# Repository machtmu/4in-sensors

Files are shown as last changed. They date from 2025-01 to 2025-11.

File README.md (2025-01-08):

# Sensors Module Repository

Use Export KiCad Images Workflow

---

<div align="center">
  <div>
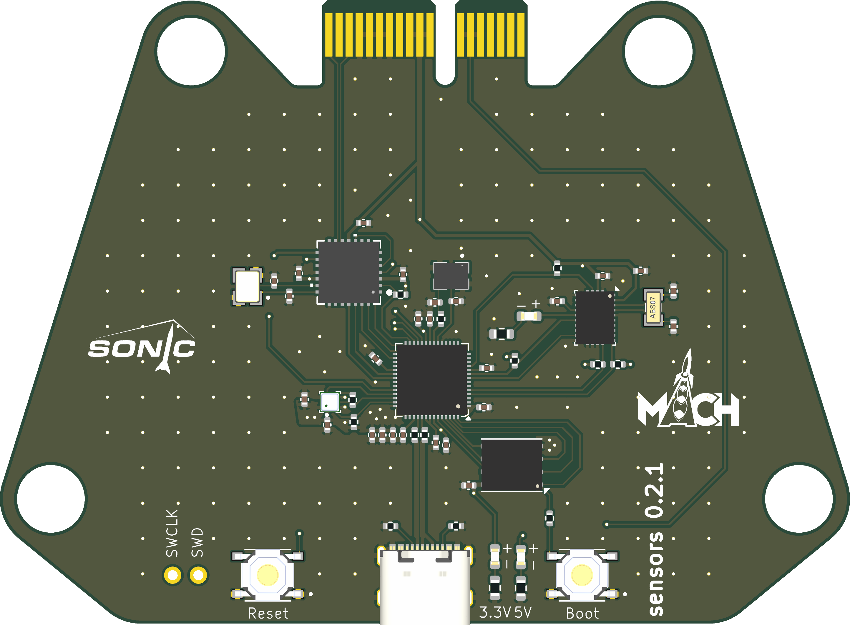
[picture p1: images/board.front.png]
    
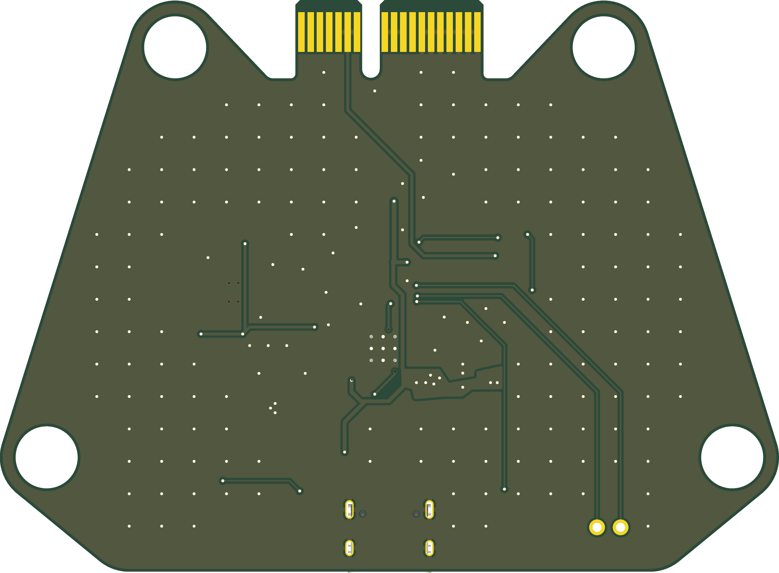
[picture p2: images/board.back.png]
    
    <p><em>3D Render</em></p>
  </div>
  <br>

  <div>
    Schematic<br>
    <p><em>Schematic</em></p>
  </div>
  <br>
  
  <div>
    Front
    Back<br>
    <em>Footprint</em>
  </div>
</div>

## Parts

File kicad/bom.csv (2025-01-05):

Reference | info | Value | Footprint | LCSC Part # | JLC Link | Digikey Link | basic? | price | Current Draw | Qty | DNP
Y2 | CAN Clock | X322516MLB4SI | X322516MLB4SI:OSC_X322516MLB4SI | C12668 | https://jlcpcb.com/partdetail/Yxc_CrystalOscillators-X322516MOB4SI/C12668 |  | no | C$0.0829 | 200 uW 3.3v | 1
Y1 | BNO055 Crystal | ABS07-32.768KHZ-T | ABS07-32.768KHZ-T:XTAL_ABS07-32.768KHZ-T | C130253 | https://jlcpcb.com/partdetail/AbraconLlc-ABS07_32_768KHZT/C130253 |  | no | C$0.6839 | 0.5 uW 3.3v | 1
X1 | MCU Crystal | ABM8-272-T3 | ABM8-272-T3:ABM8-272-T3_ABR | C20625731 | https://jlcpcb.com/partdetail/AbraconLlc-ABM8_272T3/C20625731 |  | no | C$0.6692 | 200 uW 3.3v | 1
U9 | CAN Controller/Tranceiver | MCP25625T-E/ML | MCP25625T_E_ML:QFN28_6X6MC_MCH | C191253 | https://jlcpcb.com/partdetail/MicrochipTech-MCP25625T_EML/C191253 |  | no | C$2.9424 | Con=10mA, Tra=70mA | 1
U8 | BNO055 | BNO055 | Package_LGA:LGA-28_5.2x3.8mm_P0.5mm | C93216 | https://jlcpcb.com/partdetail/BoschSensortec-BNO055/C93216 |  | no | C$14.0435 | 12.3mA | 1
U5 | BMP388 | BMP388 | BMP388:PQFN50P200X200X80-10N | C779278 | https://jlcpcb.com/partdetail/BoschSensortec-BMP388/C779278 |  | no | C$2.3423 | 800uA | 1
U4 | Flash | W25Q128JVP | Package_SON:WSON-8-1EP_6x5mm_P1.27mm_EP3.4x4.3mm | C190862 | https://jlcpcb.com/partdetail/WinbondElec-W25Q128JVPIQ/C190862 |  | no | C$1.0737 | 25mA | 1
U2 | MCU | RP2040 | Package_DFN_QFN:QFN-56-1EP_7x7mm_P0.4mm_EP3.2x3.2mm | C2040 | https://jlcpcb.com/partdetail/RaspberryPi-RP2040/C2040 |  | no | C$1.4190 | 20mA | 1
S1,S2 | Button | TS-1187A-B-A-B | TS-1187A-B-A-B:SW_TS-1187A-B-A-B | C318884 | https://jlcpcb.com/partdetail/XKBConnection-TS_1187A_B_AB/C318884 |  | yes | C$0.0242 |  | 2
R83,R87,R91 | 10k ohm | 10k | Resistor_SMD:R_0402_1005Metric | C25744 | https://jlcpcb.com/partdetail/26487-0402WGF1002TCE/C25744 |  | yes | C$0.0007 |  | 3
R220,R221,R222,R223 | 4.7k ohm | 4.7k | Resistor_SMD:R_0402_1005Metric | C25900 | https://jlcpcb.com/partdetail/26643-0402WGF4701TCE/C25900 |  | yes | C$0.0007 |  | 4
R203,R204 | 27 ohm | 27 | Resistor_SMD:R_0402_1005Metric | C25100 | https://jlcpcb.com/partdetail/25843-0402WGF270JTCE/C25100 |  | no | C$0.0007 |  | 2
R12,R30 | 1k ohm | 1k | Resistor_SMD:R_0402_1005Metric | C11702 | https://jlcpcb.com/partdetail/12256-0402WGF1001TCE/C11702 |  | yes | C$0.0007 |  | 2
R89 | 150 ohm | 150 | Resistor_SMD:R_0603_1608Metric | C22808 | https://jlcpcb.com/partdetail/23535-0603WAF1500T5E/C22808 |  | yes | C$0.0013 |  | 1
J6 | USB-C | USB_C_Receptacle_USB2.0_16P | Connector_USB:USB_C_Receptacle_Palconn_UTC16-G | C2765186 | https://jlcpcb.com/partdetail/ShouHan-TYPE_C_16PIN_2MD_073/C2765186 |  | no | C$0.0738 |  | 1
J4 | two headders | Conn_01x02 | Connector_PinHeader_2.54mm:PinHeader_1x02_P2.54mm_Vertical | n/a | n/a |  | n/a | n/a |  | 1 | DNP
J1 | PCIe fingers | Bus_PCI_Express_x1 | Connector_PCBEdge:BUS_PCIexpress_x1 | n/a | n/a |  | n/a | n/a |  | 1 | DNP
D88 | Red LED | LED | LED_SMD:LED_0603_1608Metric | C2286 | https://jlcpcb.com/partdetail/Hubei_KentoElec-KT0603R/C2286 |  | yes | C$0.0075 |  | 1
C85,C86,C94,C95 | 22pF Cap | 22p | Capacitor_SMD:C_0402_1005Metric | C1555 | https://jlcpcb.com/partdetail/1907-0402CG220J500NT/C1555 |  | yes | C$0.0077 |  | 4
C84,C208,C210 | 1uF Cap | 1u | Capacitor_SMD:C_0402_1005Metric | C52923 | https://jlcpcb.com/partdetail/53938-CL05A105KA5NQNC/C52923 |  | yes | C$0.0041 |  | 3
C40,C50,C51,C81,C82,C90,C92,C93,C206,C207,C209,C211,C212,C213,C214,C215,C216 | 100nF Cap | 100n | Capacitor_SMD:C_0402_1005Metric | C307331 | https://jlcpcb.com/partdetail/291005-CL05B104KB54PNC/C307331 |  | yes | C$0.0077 |  | 17
C10,C11 | 15pF Cap | 15p | Capacitor_SMD:C_0402_1005Metric | C1548 | https://jlcpcb.com/partdetail/1900-0402CG150J500NT/C1548 |  | yes | C$0.0013 |  | 2

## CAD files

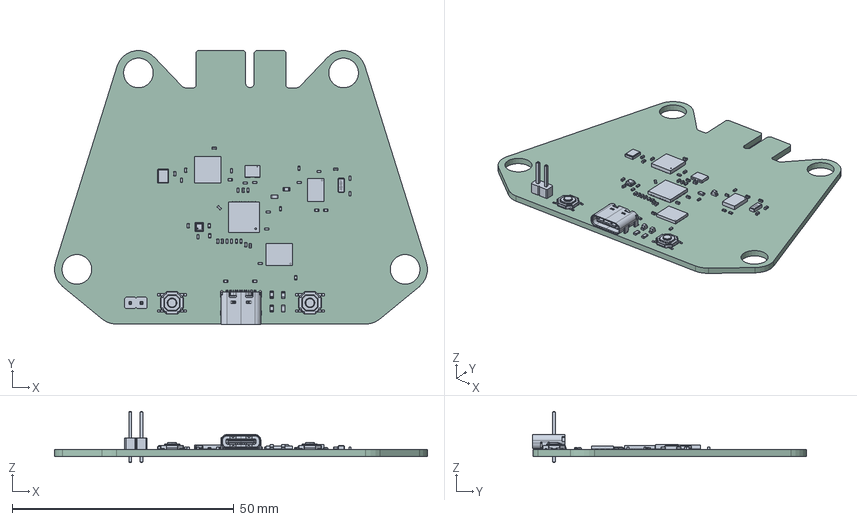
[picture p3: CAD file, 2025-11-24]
images/board.step
84.1 x 61.9 x 11.5 mm
WSON-8-1EP_6x5mm_P1.27mm_EP3.4x4.3mm
C_0402_1005Metric x 26
R_0402_1005Metric x 13
BMP388
X322516MLB4SI
TS-1187A-B-A-B x 2
R_0603_1608Metric x 3
LED_0603_1608Metric x 3
QFN28_6X6MC_MCH
USB_C_Receptacle_GCT_USB4105-xx-A_16P_TopMnt_Horizontal
ABM8-272-T3_ABR
LGA-28_5.2x3.8mm_P0.5mm
ABS07-32.768KHZ-T
QFN-56-1EP_7x7mm_P0.4mm_EP3.2x3.2mm
PinHeader_1x02_P2.54mm_Vertical
sensors_PCB

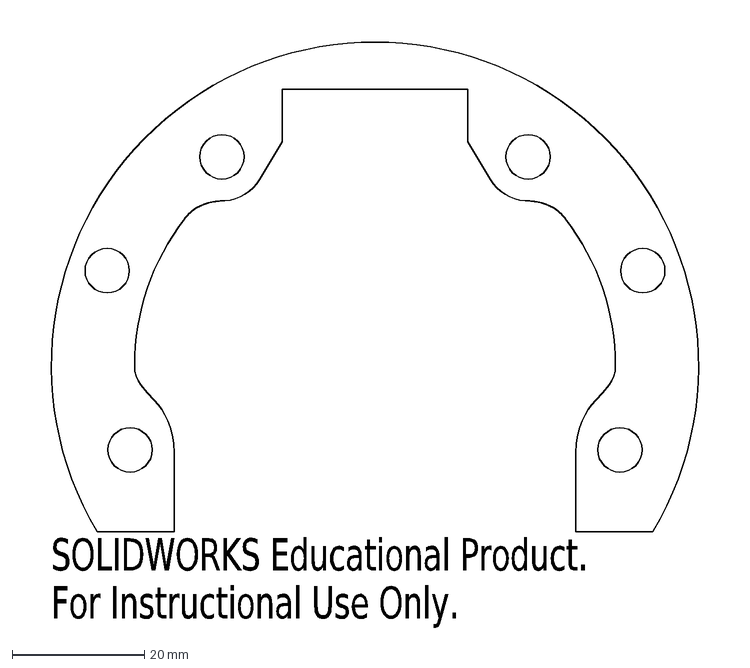
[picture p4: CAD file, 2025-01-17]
kicad/rack.DXF
SOLIDWORKS Educational Product.
For Instructional Use Only.

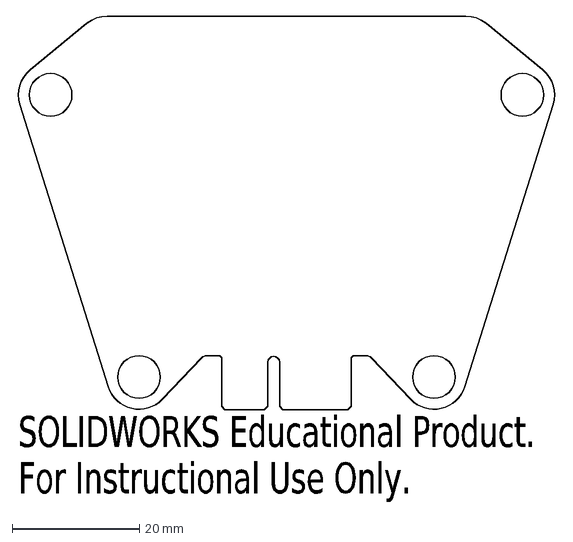
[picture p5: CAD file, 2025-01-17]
kicad/card.DXF
SOLIDWORKS Educational Product.
For Instructional Use Only.

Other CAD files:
solidworks/sensors.step

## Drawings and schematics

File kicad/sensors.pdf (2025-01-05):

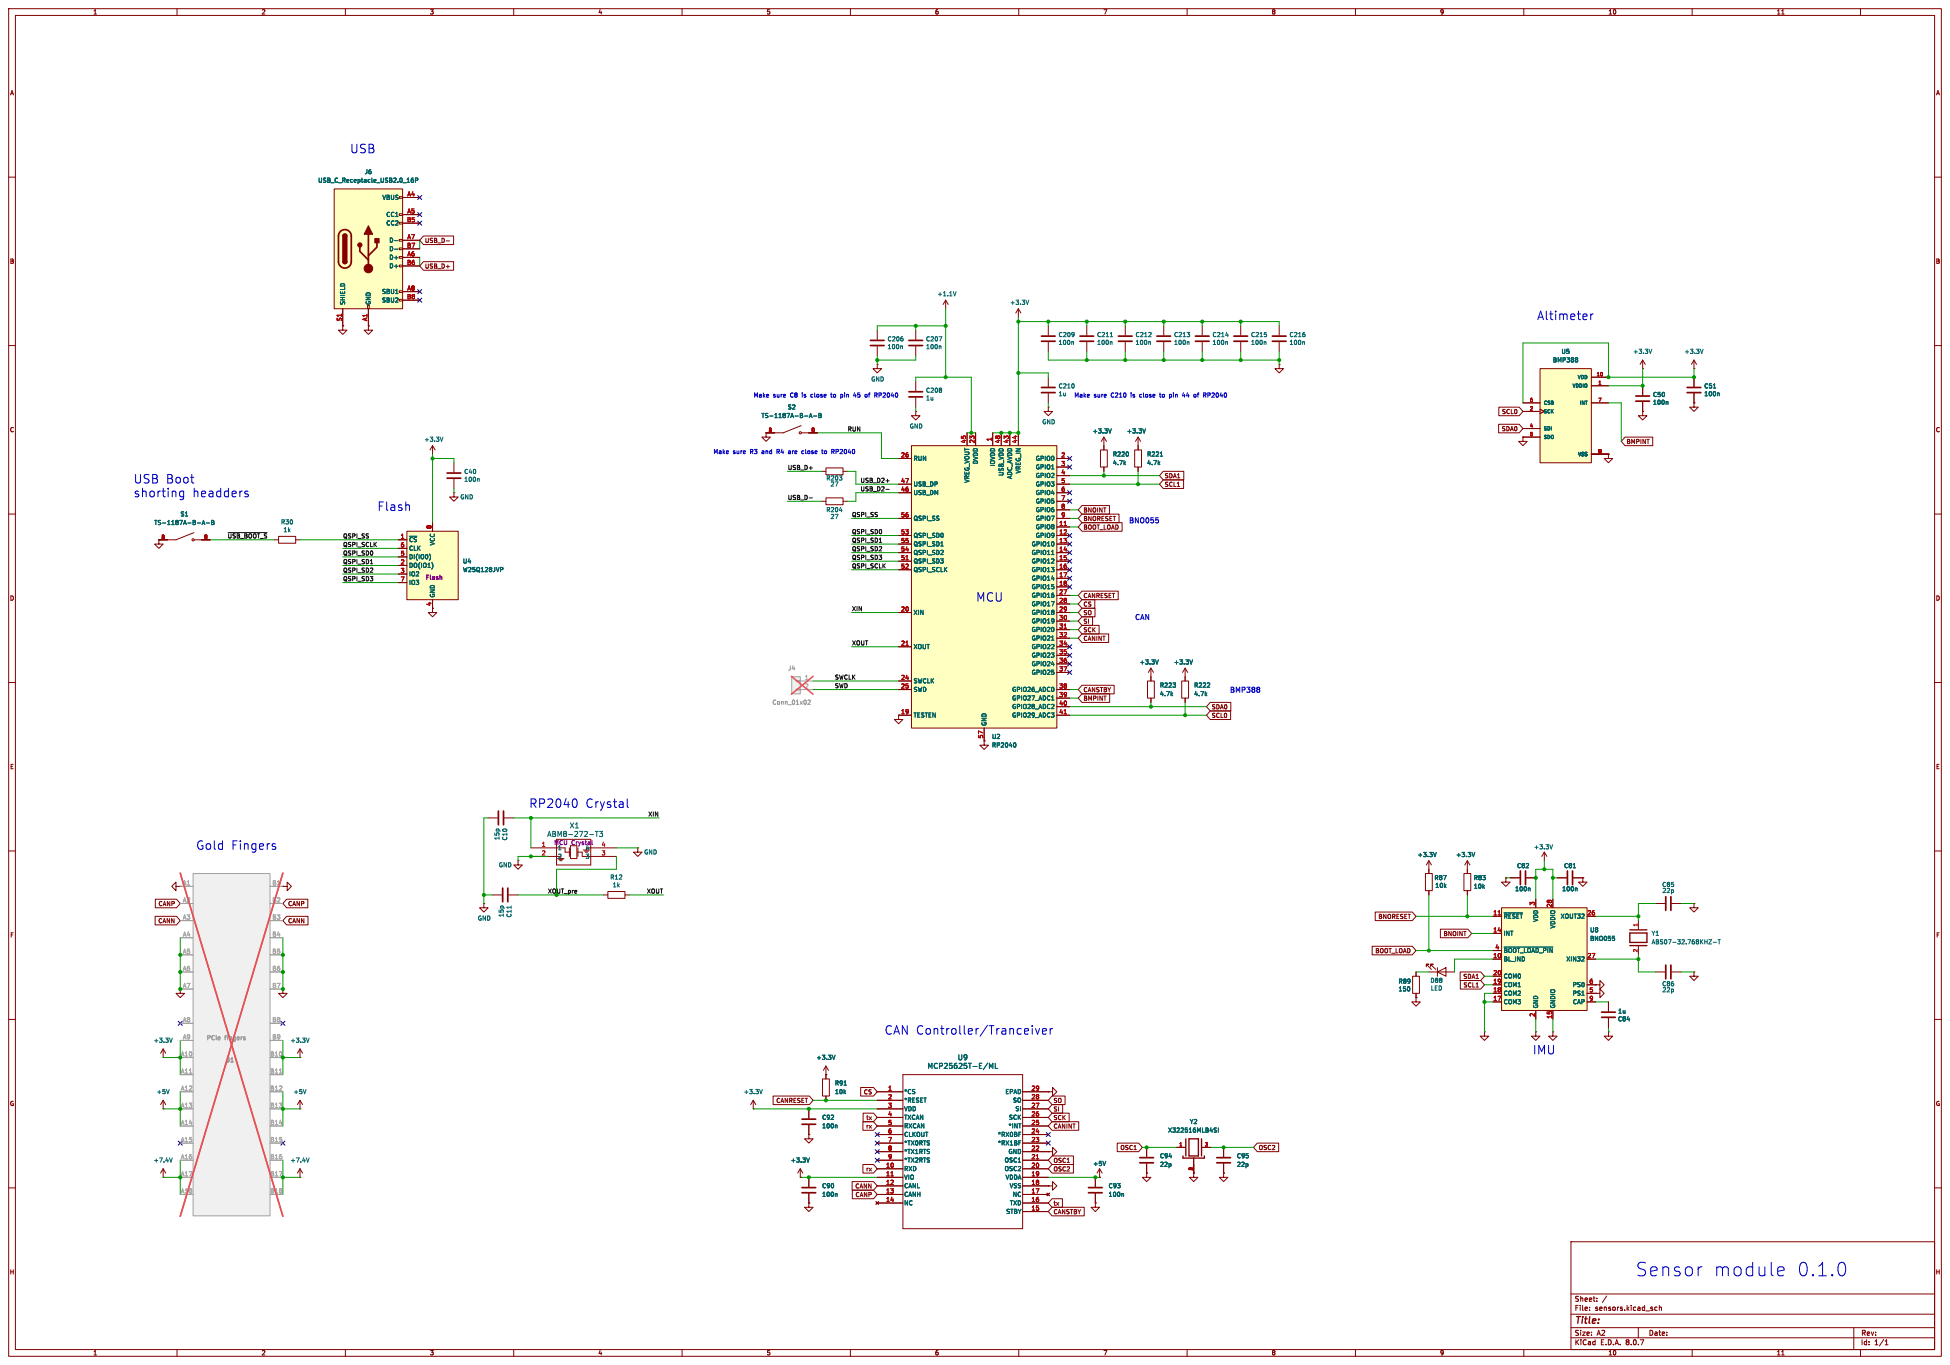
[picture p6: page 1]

Make sure R3 and R4 are close to RP2040 Make sure C8 is close to pin 45 of RP2040

Make sure C210 is close to pin 44 of RP2040 CAN Controller/Tranceiver

1 GPIO8 11 GPIO9 12 GPIO10 13 GPIO11 14 GPIO12 15 GPIO13 16 GPIO14 17 GPIO15 18 TESTEN 19 GPIO0 2 XIN 20 XOUT 21 DVDD 23 SWCLK 24 SWD 25 RUN 26 GPIO16 27 GPIO17 28 GPIO18 29 GPIO1 3 GPIO19 30 GPIO20 31 GPIO21 32 GPIO22 34 GPIO23 35 GPIO24 36 GPIO25 37 GPIO26_ADC0 38 GPIO27_ADC1 39 GPIO2 4 GPIO28_ADC2 40 GPIO29_ADC3 41 ADC_AVDD 43 VREG_IN 44 VREG_VOUT 45 USB_DM 46 USB_DP 47 USB_VDD 48 GPIO3 5 QSPI_SD3 51 QSPI_SCLK 52 QSPI_SD0 53 QSPI_SD2 54 QSPI_SD1 55 QSPI_SS 56 GND 57 GPIO4 6 GPIO5 7 GPIO6 8 GPIO7 9 U2 RP2040 R89

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

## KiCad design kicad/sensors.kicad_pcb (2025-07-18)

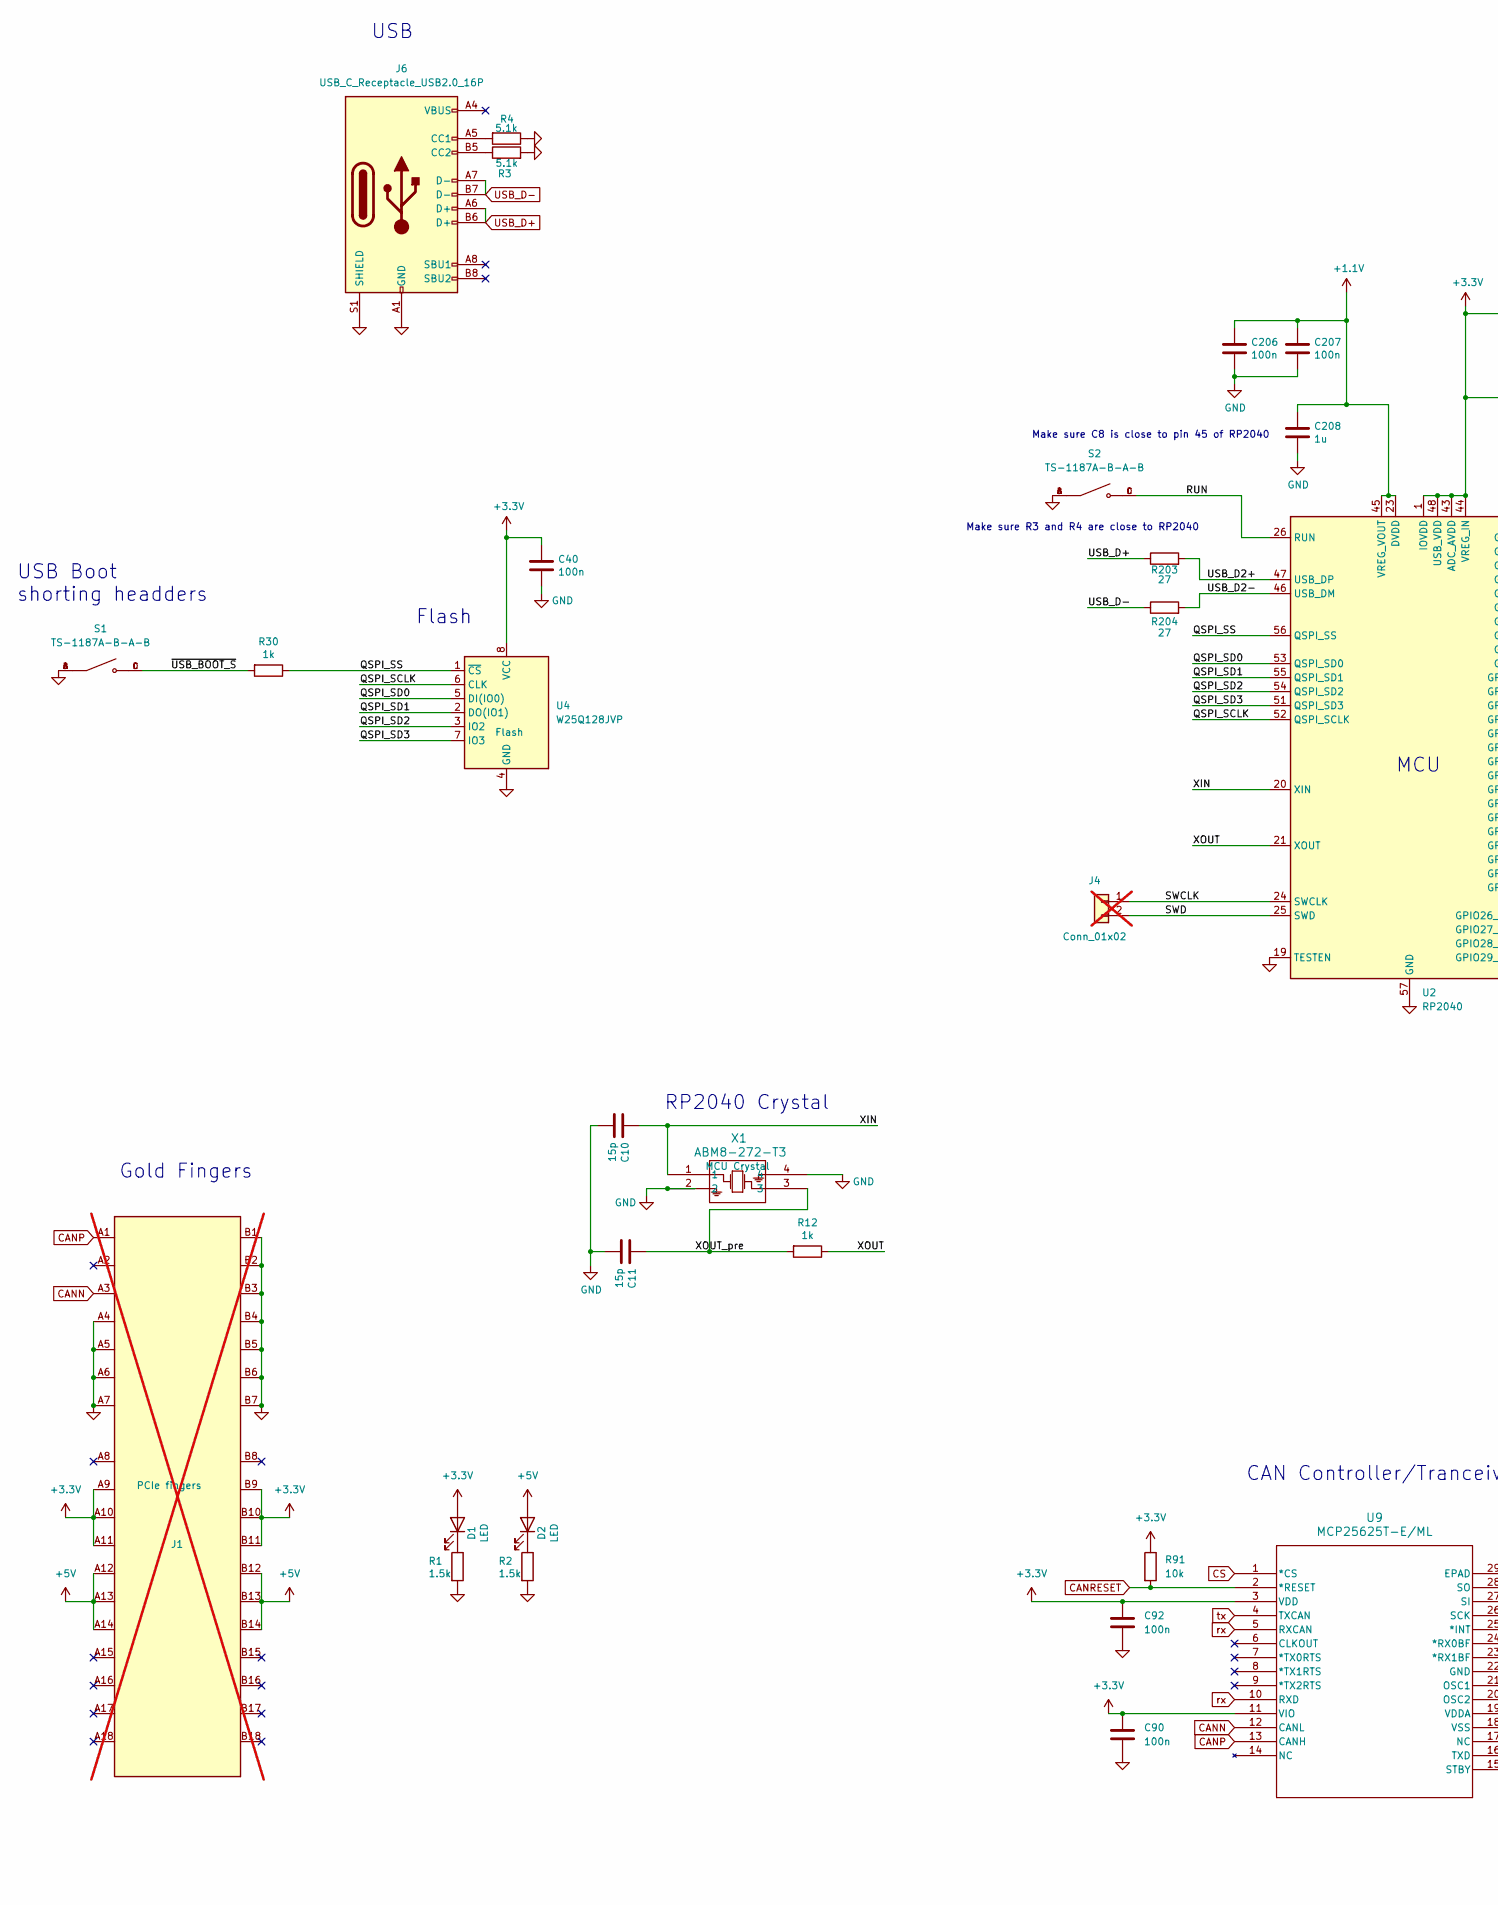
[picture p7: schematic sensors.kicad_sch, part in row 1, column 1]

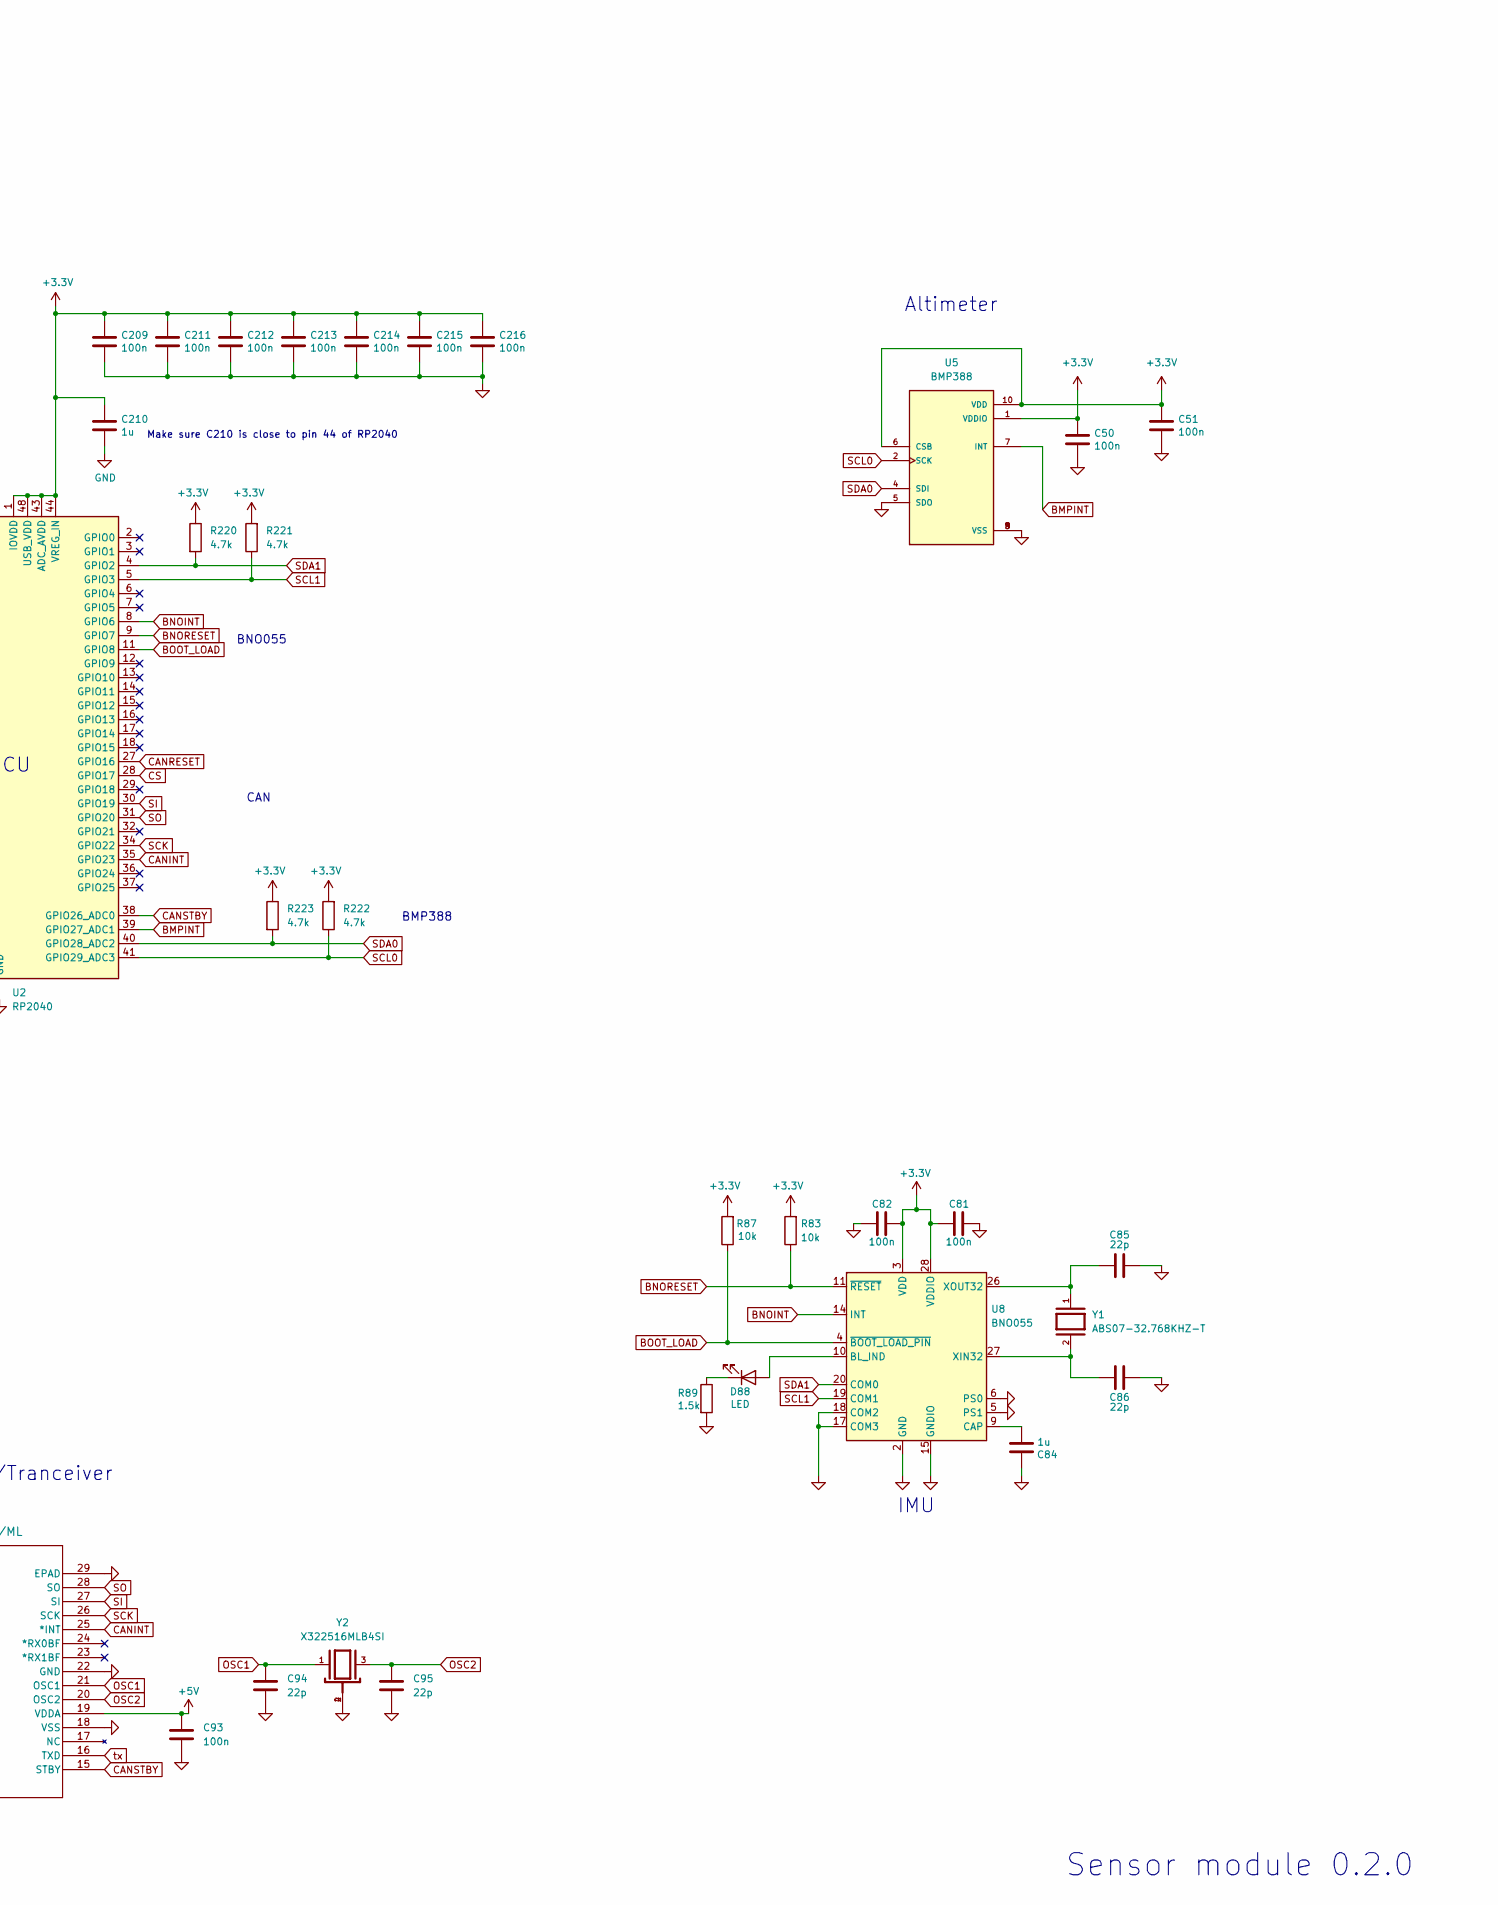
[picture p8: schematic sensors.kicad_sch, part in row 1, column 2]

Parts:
C10, C11: 15p; C_0402_1005Metric; LCSC Part # C1548
C40, C50, C51, C81, C82, C90, C92, C93, C206, C207, C209, C211, C212, C213, C214, C215, C216: 100n; C_0402_1005Metric; LCSC Part # C307331
C84, C208, C210: 1u; C_0402_1005Metric; LCSC Part # C52923
C85, C86, C94, C95: 22p; C_0402_1005Metric; LCSC Part # C1555
D1, D2, D88: LED; LED_0603_1608Metric; LCSC Part # C2286
J1: Bus_PCI_Express_x1; BUS_PCIexpress_x1; LCSC Part # n/a; not fitted
J4: Conn_01x02; PinHeader_1x02_P2.54mm_Vertical; LCSC Part # n/a; not fitted
J6: USB_C_Receptacle_USB2.0_16P; USB_C_Receptacle_Palconn_UTC16-G; LCSC Part # C2765186
R1, R2, R89: 1.5k; R_0603_1608Metric; LCSC Part # C22808
R3, R4: 5.1k; R_0402_1005Metric; LCSC Part # C25905
R12, R30: 1k; R_0402_1005Metric; LCSC Part # C11702
R83, R87, R91: 10k; R_0402_1005Metric; LCSC Part # C25744
R203, R204: 27; R_0402_1005Metric; LCSC Part # C25100
R220, R221, R222, R223: 4.7k; R_0402_1005Metric; LCSC Part # C25900
S1, S2: TS-1187A-B-A-B; SW_TS-1187A-B-A-B; PARTREV A0; LCSC Part # C318884
U2: RP2040; QFN-56-1EP_7x7mm_P0.4mm_EP3.2x3.2mm; LCSC C2040
U4: W25Q128JVP; WSON-8-1EP_6x5mm_P1.27mm_EP3.4x4.3mm; LCSC C190862
U5: BMP388; PQFN50P200X200X80-10N; PARTREV 1.1; LCSC Part # C779278
U8: BNO055; LGA-28_5.2x3.8mm_P0.5mm; LCSC C93216
U9: MCP25625T-E/ML; QFN28_6X6MC_MCH; LCSC Part # C191253
X1: ABM8-272-T3; ABM8-272-T3_ABR; LCSC Part # C20625731
Y1: ABS07-32.768KHZ-T; XTAL_ABS07-32.768KHZ-T; PARTREV 08.19.15; LCSC Part # C130253
Y2: X322516MLB4SI; OSC_X322516MLB4SI; PARTREV N/A; LCSC Part # C12668

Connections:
+1.1V: C206.1, C207.1, C208.1, U2.23 (DVDD), U2.45 (VREG_VOUT), U2.50 (DVDD)
+3.3V: C40.1, C50.1, C51.1, C81.1, C82.2, C90.1, C92.1, C209.1, C210.1, C211.1, C212.1, C213.1, C214.1, C215.1, C216.1, D1.2 (A), J1.A9 (+3.3V), J1.A10 (+3.3V), J1.A11 (~PERST), J1.B9 (JTAG1), J1.B10 (3.3Vaux), J1.B11 (~WAKE), R83.2, R87.2, R91.1, R220.1, R221.2, R222.2, R223.1, U2.1 (IOVDD), U2.10 (IOVDD), U2.22 (IOVDD), U2.33 (IOVDD), U2.42 (IOVDD), U2.43 (ADC_AVDD), U2.44 (VREG_IN), U2.48 (USB_VDD), U2.49 (IOVDD), U4.8 (VCC), U5.1 (VDDIO), U5.6 (CSB), U5.10 (VDD), U8.3 (VDD), U8.28 (VDDIO), U9.3 (VDD), U9.11 (VIO)
+5V: C93.1, D2.2 (A), J1.A12 (GND), J1.A13 (REFCLK+), J1.A14 (REFCLK-), J1.B12 (RSVD), J1.B13 (GND), J1.B14 (PETp0), U9.19 (VDDA)
/QSPI_SCLK: U2.52 (QSPI_SCLK), U4.6 (CLK)
/QSPI_SD0: U2.53 (QSPI_SD0), U4.5 (DI(IO0))
/QSPI_SD1: U2.55 (QSPI_SD1), U4.2 (DO(IO1))
/QSPI_SD2: U2.54 (QSPI_SD2), U4.3 (IO2)
/QSPI_SD3: U2.51 (QSPI_SD3), U4.7 (IO3)
/QSPI_SS: R30.1, U2.56 (QSPI_SS), U4.1 (~CS)
/RUN: S2.C, S2.D, U2.26 (RUN)
/SWCLK: J4.1, U2.24 (SWCLK)
/SWD: J4.2, U2.25 (SWD)
/USB_D2+: R203.2, U2.47 (USB_DP)
/USB_D2-: R204.2, U2.46 (USB_DM)
/XIN: C10.1, U2.20 (XIN), X1.1
/XOUT: R12.1, U2.21 (XOUT)
/XOUT_pre: C11.1, R12.2, X1.3
/~USB_BOOT_S: R30.2, S1.C, S1.D
BMPINT: U2.39 (GPIO27_ADC1), U5.7 (INT)
BNOINT: U2.8 (GPIO6), U8.14 (INT)
BNORESET: R83.1, U2.9 (GPIO7), U8.11 (~RESET)
BOOT_LOAD: R87.1, U2.11 (GPIO8), U8.4 (~BOOT_LOAD_PIN)
CANINT: U2.35 (GPIO23), U9.25 (*INT)
CANN: J1.A3 (+12V), U9.12 (CANL)
CANP: J1.A1 (~PRSNT1), U9.13 (CANH)
CANRESET: R91.2, U2.27 (GPIO16), U9.2 (*RESET)
CANSTBY: U2.38 (GPIO26_ADC0), U9.15 (STBY)
CS: U2.28 (GPIO17), U9.1 (*CS)
GND: C10.2, C11.2, C40.2, C50.2, C51.2, C81.2, C82.1, C84.1, C85.2, C86.1, C90.2, C92.2, C93.2, C94.2, C95.2, C206.2, C207.2, C208.2, C209.2, C210.2, C211.2, C212.2, C213.2, C214.2, C215.2, C216.2, J1.A4 (GND), J1.A5 (JTAG2), J1.A6 (JTAG3), J1.A7 (JTAG4), J1.B1 (+12V), J1.B2 (+12V), J1.B3 (+12V), J1.B4 (GND), J1.B5 (SMCLK), J1.B6 (SMDAT), J1.B7 (GND), J6.A1 (GND), J6.A12 (GND), J6.B1 (GND), J6.B12 (GND), J6.S1 (SHIELD), R1.2, R2.2, R3.2, R4.1, R89.2, S1.A, S1.B, S2.A, S2.B, U2.19 (TESTEN), U2.57 (GND), U4.4 (GND), U5.3 (VSS), U5.5 (SDO), U5.8 (VSS), U5.9 (VSS), U8.2 (GND), U8.5 (PS1), U8.6 (PS0), U8.15 (GNDIO), U8.16 (GNDIO), U8.17 (COM3), U8.18 (COM2), U8.25 (GNDIO), U9.18 (VSS), U9.22 (GND), U9.29 (EPAD), X1.2, X1.4, Y2.2, Y2.4
unnamed: D1.1 (K), R1.1
unnamed: D2.1 (K), R2.1
unnamed: D88.2 (A), U8.10 (BL_IND)
unnamed: D88.1 (K), R89.1
unnamed: J6.A5 (CC1), R4.2
unnamed: J6.B5 (CC2), R3.1
unnamed: C84.2, U8.9 (CAP)
unnamed: C86.2, U8.27 (XIN32), Y1.2
unnamed: C85.1, U8.26 (XOUT32), Y1.1
OSC1: C94.1, U9.21 (OSC1), Y2.1
OSC2: C95.1, U9.20 (OSC2), Y2.3
SCK: U2.34 (GPIO22), U9.26 (SCK)
SCL0: R222.1, U2.41 (GPIO29_ADC3), U5.2 (SCK)
SCL1: R221.1, U2.5 (GPIO3), U8.19 (COM1)
SDA0: R223.2, U2.40 (GPIO28_ADC2), U5.4 (SDI)
SDA1: R220.2, U2.4 (GPIO2), U8.20 (COM0)
SI: U2.30 (GPIO19), U9.27 (SI)
SO: U2.31 (GPIO20), U9.28 (SO)
USB_D+: J6.A6 (D+), J6.B6 (D+), R203.1
USB_D-: J6.A7 (D-), J6.B7 (D-), R204.1
rx: U9.5 (RXCAN), U9.10 (RXD)
tx: U9.4 (TXCAN), U9.16 (TXD)

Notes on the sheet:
Make sure C210 is close to pin 44 of RP2040
Make sure C8 is close to pin 45 of RP2040
RP2040 Crystal
Altimeter
BNO055
BMP388
IMU
USB
Make sure R3 and R4 are close to RP2040
CAN
USB Boot shorting headders
Sensor module 0.2.0
Gold Fingers
MCU
CAN Controller/Tranceiver
Flash

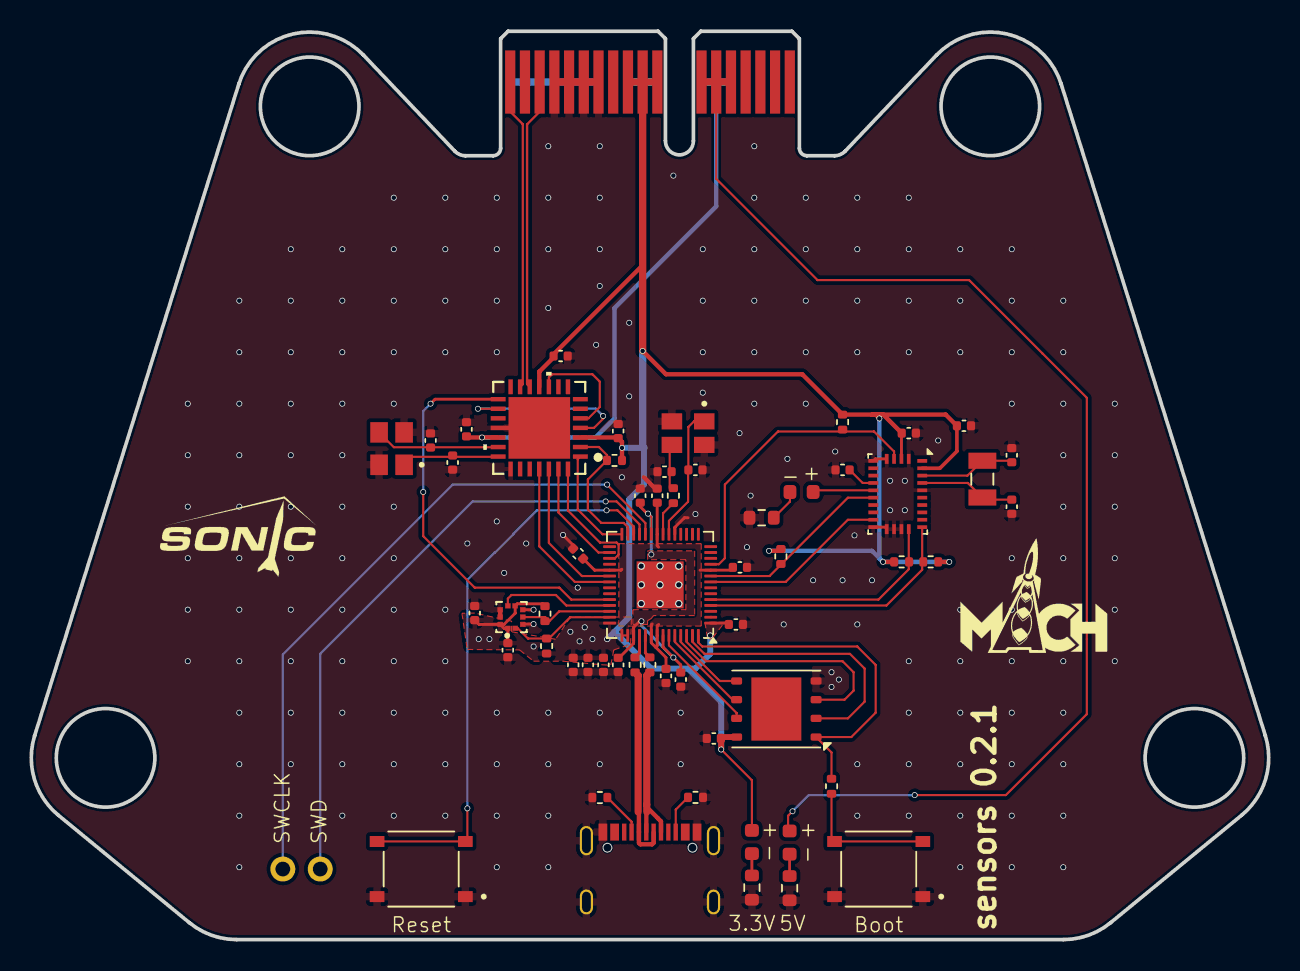
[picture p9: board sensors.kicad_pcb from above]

Board: 2 copper layers, 84.1 x 61.7 mm, 58 parts (1 on the bottom side), 51 nets.

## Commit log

2025-01-07 Auto-exported schematic, PCB, and 3D model
    [board.step]
2025-01-08 Auto-exported schematic
    [board.step]
2025-01-15 Update board to 0.2.0
    [card.DXF, rack.DXF, sensors.kicad_pcb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]
2025-01-15 add USBC resistors, power status LEDs, silk screen indicator, change SPI pins
    [sensors.kicad_pcb, sensors.kicad_sch]
2025-01-15 update BOM, generate new production files
    [bom.csv, designators.csv, positions.csv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]
2025-01-17 finalize board, update production files
2025-02-05 Update images
    [board.step]
2025-03-08 export step file
    [reference_pcb.step]
2025-03-08 update to kicad 9, update LED resistors
    [sensors.kicad_pcb, sensors.kicad_sch]
2025-03-08 update PCB editor
    [sensors.kicad_pcb]
2025-07-18 move LEDs and text to bottom update to 0.2.1
    [bom.csv, designators.csv, positions.csv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]
